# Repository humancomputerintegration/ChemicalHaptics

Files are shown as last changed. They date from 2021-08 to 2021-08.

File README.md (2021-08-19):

# Chemical Haptics: Rendering Haptic Sensations via Topical Stimulants

This is the repository for silicone mold 3D Print files, hardware schematics, and code used in the wearable device of "**Chemical Haptics: Rendering Haptic Sensations via Topical Stimulants**" paper (ACM UIST2021). Additionally, we've included the anonymized data from our user study tracking participants' perceived sensations as chemicals were applied and then removed.

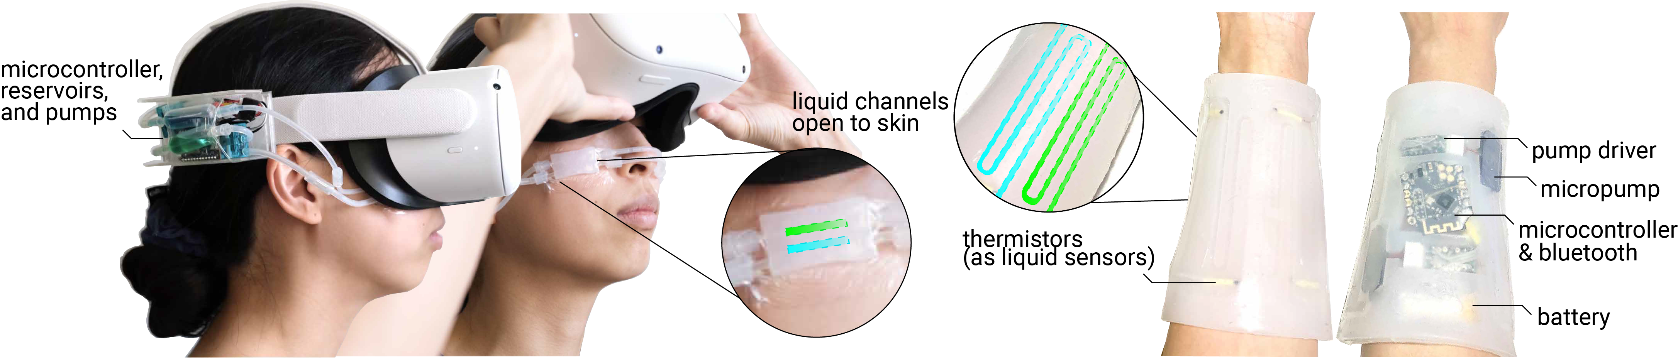
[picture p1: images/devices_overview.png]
devices overview


## Hardware

Below are the specific components used in our device design, but these can be easily replaced by similar components.

### Electronics

* Microcontroller - Beetle BLE, DFRobot
* Pump Driver - MP6 Driver, ServoFlo
* Thermistors -  NTC Thermistor 10k Bead, DigiKey

### Pumps

* Micropump, MP6, ServoFlo
* (Alternative) Micro Vacuum Pump - [Amazon Link](https://www.amazon.com/Artshu-Vacuum-Negative-Pressure-Cupping/dp/B08JP94FQ7)

### Tubing

* 3mm Outer Diameter Silicone Tubing, [Amazon Link](https://www.amazon.com/Quickun-Silicone-Brewing-Kegerator-Aquaponics/dp/B091T4C1Q8)
* 3mm Inner Diameter Silicone Tubing (good for connectors), [Amazon Link](https://www.amazon.com/Feelers-High-Strength-Silicone-Silicon-Winemaking/dp/B096M2TL23)

## Silicone Mold Design

In this repo we include the STL files of our [3D printed molds](./3D_models) that were used to cast the silicone pieces used in our wearable device. The channels in the silicone can be designed in any way and take variable shape. We used Dragon Skin FX-Pro Silicone, but any silicone of similar hardness can be used. Below you'll find more specific guidelines for using these silicone pieces.

### Central to Peripheral Patch

In the headset design, we demonstrate having a central control unit (with all necessary hardware, reservoirs, and pumps) delivering chemicals to peripheral silicone patches via tubes.

These patches can be adhered to the skin with skin safe tape ([Amazon Link](https://www.amazon.com/Aftercare-Waterproof-Protection-Tape%EF%BC%8CWound-Resistant/dp/B096B464TX/)), but should also be compressed to avoid leakage. Alternatively, bandage wrap ([Amazon Link](https://www.amazon.com/dp/B08YNHSMWZ/))  can be used to wrap around the skin area + silicone patch to apply adequate compression. 

### Self-contained Sleeve

In the sleeve design, cavities are incorporated into the mold for electronics components. Wires/Thermistors can be weaved through silicone or channels can be dedicated for them too. Silicone can be poured over components or tape can cover compartments for wearability. 

Once the full silicone piece is cured, we recommend curing the ends of the sleeve together with additional silicone.

Alternatively, you can cast silicone with velcro on the sleeve edges. This can be used to create sleeves of variable diameters.

## Study 1 Data: How Chemicals Feel

Anonymized data is included in the folder "study_data". You can read more about how to interpret the data in [Processing TCATA Data](./study_data/README.md).

Additionally, if you'd like to replicate our temporal check all that apply study, you can use the web app we built which is available in a separate repo here: [TCATA Web App](https://github.com/xjasminelu/tcata_chemhaptics).

## Citation

When using or building upon this device/work in an academic publication, please consider citing as follows:

Jasmine Lu, Ziwei Liu, Jas Brooks, Pedro Lopes. 2021. Chemical Haptics: Rendering Haptic Sensations via Topical Stimulants. In Proceedings of ACM Symposium on User Interface Software and Technology 2021 (UIST’2021). Association for Computing Machinery, New York, NY, USA. https://doi.org/10.1145/3472749.3474747

## Contact
For questions or if something is wrong with this repository, contact jasminelu@uchicago.edu

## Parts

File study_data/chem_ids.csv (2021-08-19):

Participant | ID | Chemical
P1 | A1 | SAN
P1 | A2 | MEN
P1 | A3 | MET
P1 | A4 | CIN
P1 | A5 | WAT
P1 | A6 | CAP
P1 | A7 | LID
P1 | B1 | LID
P1 | B2 | SAN
P1 | B3 | CIN
P1 | B4 | MET
P1 | B5 | WAT
P1 | B6 | MEN
P1 | B7 | CAP
P1 | C1 | CIN
P1 | C2 | CAP
P1 | C3 | SAN
P1 | C4 | WAT
P1 | C5 | MET
P1 | C6 | MEN
P1 | C7 | LID
P2 | A1 | MET
P2 | A2 | LID
P2 | A3 | MEN
P2 | A4 | SAN
P2 | A5 | WAT
P2 | A6 | CAP
P2 | A7 | CIN
P2 | B1 | WAT
P2 | B2 | MET
P2 | B3 | MEN
P2 | B4 | LID
P2 | B5 | SAN
P2 | B6 | CIN
P2 | B7 | CAP
P2 | C1 | SAN
P2 | C2 | WAT
P2 | C3 | CIN
P2 | C4 | CAP
P2 | C5 | MET
P2 | C6 | MEN
P2 | C7 | LID
P3 | A1 | CAP
P3 | A2 | WAT
P3 | A3 | MEN
P3 | A4 | CIN
P3 | A5 | LID
P3 | A6 | SAN
P3 | A7 | MET
P3 | B1 | WAT
P3 | B2 | CAP
P3 | B3 | CIN
P3 | B4 | MET
P3 | B5 | SAN
P3 | B6 | LID
P3 | B7 | MEN
P3 | C1 | MET
P3 | C2 | WAT
P3 | C3 | MEN
P3 | C4 | CAP
P3 | C5 | CIN
P3 | C6 | SAN
P3 | C7 | LID
P4 | A1 | MEN
P4 | A2 | CIN
P4 | A3 | LID
P4 | A4 | CAP
P4 | A5 | WAT
P4 | A6 | SAN
P4 | A7 | MET
P4 | B1 | CIN
P4 | B2 | CAP
P4 | B3 | WAT
P4 | B4 | MEN
P4 | B5 | LID
P4 | B6 | SAN
P4 | B7 | MET
P4 | C1 | WAT
P4 | C2 | MET
P4 | C3 | MEN
P4 | C4 | LID
P4 | C5 | CAP
P4 | C6 | SAN
P4 | C7 | CIN
P5 | A1 | MEN
P5 | A2 | CIN
P5 | A3 | LID
P5 | A4 | CAP
P5 | A5 | WAT
P5 | A6 | SAN
P5 | A7 | MET
P5 | B1 | CIN
P5 | B2 | CAP
P5 | B3 | WAT
P5 | B4 | MEN
P5 | B5 | LID
P5 | B6 | SAN
P5 | B7 | MET
P5 | C1 | WAT
P5 | C2 | MET
P5 | C3 | MEN
P5 | C4 | LID
P5 | C5 | CAP
P5 | C6 | SAN
P5 | C7 | CIN
P6 | A1 | MET
P6 | A2 | SAN
P6 | A3 | LID
P6 | A4 | CAP
P6 | A5 | CIN
P6 | A6 | MEN
P6 | A7 | WAT
P6 | B1 | CIN
P6 | B2 | SAN
P6 | B3 | MEN
P6 | B4 | CAP
P6 | B5 | WAT
P6 | B6 | MET
P6 | B7 | LID
P6 | C1 | CAP
P6 | C2 | MET
P6 | C3 | WAT
P6 | C4 | MEN
P6 | C5 | SAN
P6 | C6 | CIN
P6 | C7 | LID
P7 | A1 | SAN
P7 | A2 | MEN
P7 | A3 | CIN
P7 | A4 | MET
P7 | A5 | LID
P7 | A6 | WAT
P7 | A7 | CAP
P7 | B1 | MEN
P7 | B2 | LID
P7 | B3 | CIN
P7 | B4 | MET
P7 | B5 | SAN
P7 | B6 | WAT
P7 | B7 | CAP
P7 | C1 | CAP
P7 | C2 | LID
P7 | C3 | WAT
P7 | C4 | MEN
P7 | C5 | SAN
P7 | C6 | CIN
P7 | C7 | MET

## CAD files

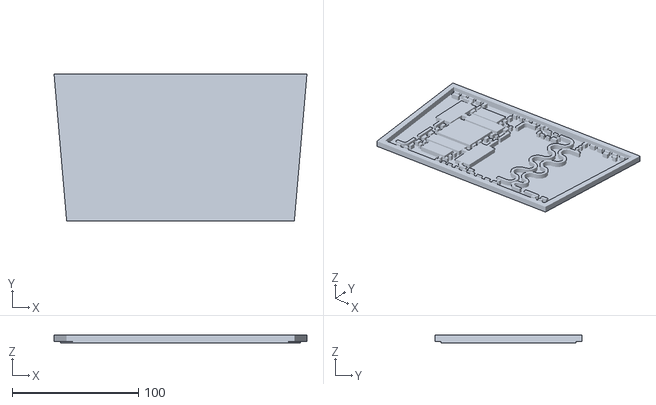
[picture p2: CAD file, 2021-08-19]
3D_models/sleeve_v3.stl
200.0 x 116.5 x 6.00

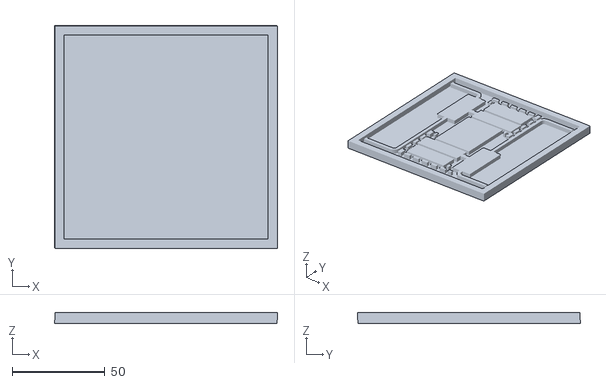
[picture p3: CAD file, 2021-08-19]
3D_models/sleeve_electronics.stl
120.2 x 120.2 x 6.00

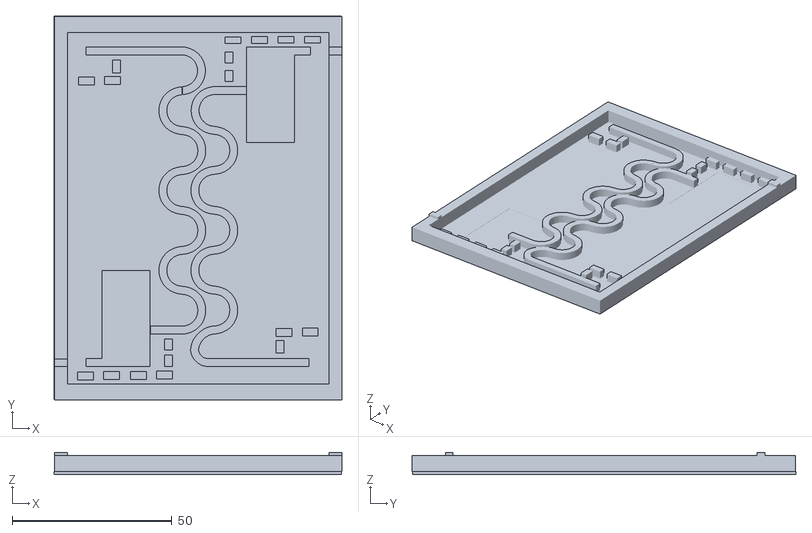
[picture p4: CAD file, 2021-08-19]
3D_models/sleeve_twochannels_v2.stl
90.2 x 120.2 x 7.00

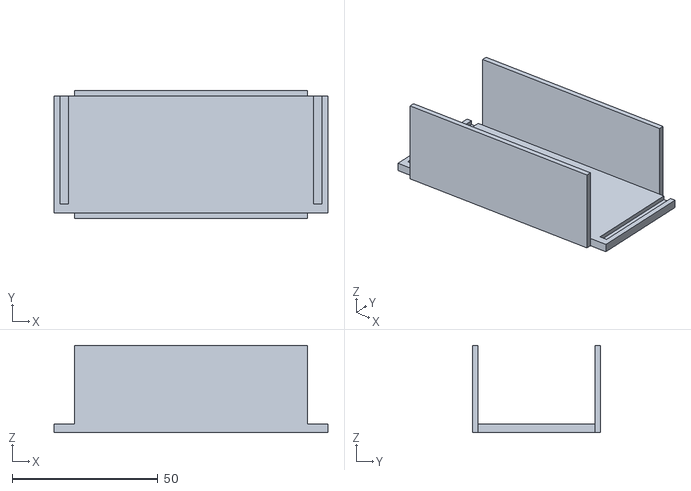
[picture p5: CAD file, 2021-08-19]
3D_models/headset_box.stl
94.0 x 44.0 x 30.0

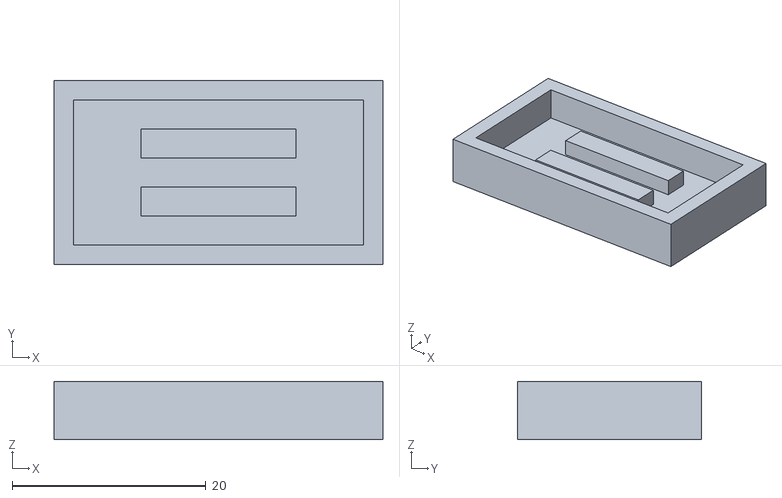
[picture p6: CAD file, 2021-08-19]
3D_models/cheekmold.stl
34.0 x 19.0 x 6.00

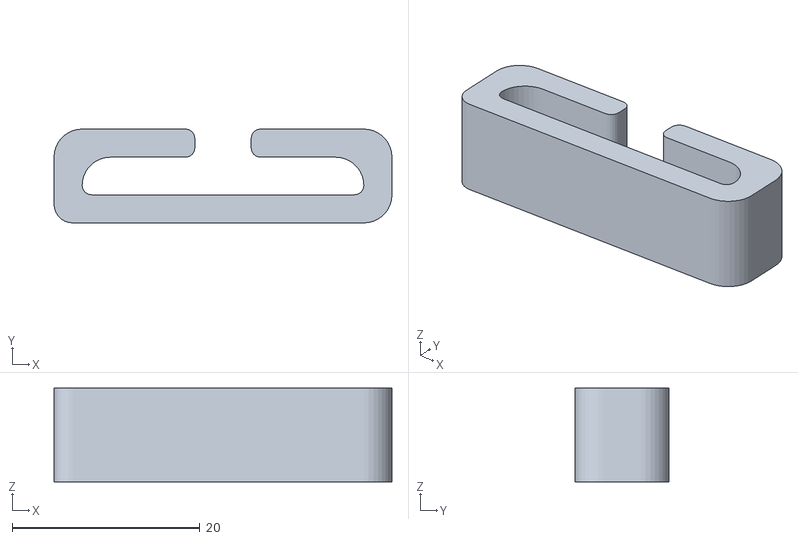
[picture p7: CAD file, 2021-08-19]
3D_models/headset_boxclip.stl
36.0 x 10.0 x 10.0

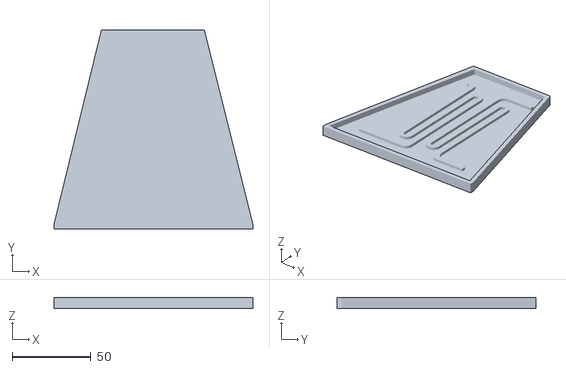
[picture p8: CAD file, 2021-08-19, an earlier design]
3D_models/sleeve_twochannels v1.stl
126.0 x 126.0 x 7.00

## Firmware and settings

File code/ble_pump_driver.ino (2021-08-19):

//Pumps driven by pins 4 and 5
#define pump1 5
#define pump2 4

int incomingByte;

void setup() {
   Serial.begin(115200);
   pinMode(pump1, OUTPUT);
   pinMode(pump2, OUTPUT);
}

void loop() {
  // Read data from BLE App to control pin turning pump on/off
  if (Serial.available() > 0) {
    incomingByte = Serial.read();

    if(incomingByte == 'A') { 
      digitalWrite(pump1, HIGH); 
    }
    if(incomingByte == 'a') { 
      digitalWrite(pump1, LOW); 
    }
    if(incomingByte == 'B') {  
      digitalWrite(pump2, HIGH); 
    }
    if(incomingByte == 'b') {
      digitalWrite(pump2, LOW); 
    }
    if(incomingByte == 'P') {
      digitalWrite(pump1, LOW); 
      digitalWrite(pump2, LOW); 
    }
  }
}

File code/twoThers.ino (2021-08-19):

// which analog pin to connect
#define THERMISTORPIN A2         
#define THERMISTORPIN1 A3   
#define THERMISTORNOMINAL 10000 
#define TEMPERATURENOMINAL 25
// how many samples to take and average, more takes longer
// but is more 'smooth'
#define NUMSAMPLES 5
// the value of the 'other' resistor
#define SERIESRESISTOR 10000
#define BCOEFFICIENT 3950    
 
int samples[NUMSAMPLES];
int samples1[NUMSAMPLES]; 

void setup(void) {
  Serial.begin(9600);
  // connect AREF to 3.3V and use that as VCC, less noisy!
  analogReference(EXTERNAL);
}
 
void loop(void) {
  uint8_t i;
  float average;
  
  uint8_t j;
  float average1;
  
  // take N samples in a row, with a slight delay
  for (i=0; i< NUMSAMPLES; i++) {
   samples[i] = analogRead(THERMISTORPIN);
   delay(5);
  }
 // take N samples in a row, with a slight delay
  for (j=0; j< NUMSAMPLES; j++) {
   samples1[j] = analogRead(THERMISTORPIN1);
   delay(5);
  }

  
  // average all the samples out
  average = 0;
  for (i=0; i< NUMSAMPLES; i++) {
     average += samples[i];
  } 
  float steinhart;
  float steinhart1;
  average /= NUMSAMPLES;
  average = 1023 / average - 1;
  average = SERIESRESISTOR / average;
  steinhart = average / THERMISTORNOMINAL;
  steinhart = log(steinhart);
  steinhart /= BCOEFFICIENT;
  steinhart += 1.0 / (TEMPERATURENOMINAL + 273.15); 
  // + (1/To)
  steinhart = 1.0 / steinhart;                 
  // Invert
  steinhart -= 273.15;                         
  // convert absolute temp to C
  
  // average all the samples out
  average1 = 0;
  for (j=0; j< NUMSAMPLES; j++) {
     average1 += samples1[j];
  }
  average1 /= NUMSAMPLES;
  average1 = 1023 / average1 - 1;
  average1 = SERIESRESISTOR / average1;
  steinhart1 = average1 / THERMISTORNOMINAL;
  steinhart1 = log(steinhart1);
  steinhart1 /= BCOEFFICIENT;
  steinhart1 += 1.0 / (TEMPERATURENOMINAL + 273.15); 
  // + (1/To)
  steinhart1 = 1.0 / steinhart1;                 
  // Invert
  steinhart1 -= 273.15;                         
  // convert absolute temp to C


  
  // print
//  Serial.print("Thermistor resistance2 "); 
  Serial.print(steinhart);
  Serial.print(", ");
  // print
//  Serial.print("Thermistor resistance1 "); 
  Serial.println(steinhart1);
  
 
//  delay(50);
}

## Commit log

2021-08-19 code and silicone mold 3D print files
    [cheekmold.stl, headset_box.stl, headset_boxclip.stl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]
2021-08-19 study data cleaned and uploaded
    [chem_codes.csv, chem_ids.csv, session_A1.csv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]
